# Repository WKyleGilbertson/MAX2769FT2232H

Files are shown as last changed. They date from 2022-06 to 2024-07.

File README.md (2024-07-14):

"# MAX2769FT2232H" 
This design was created to provide a hands-on platform for exploring GPS signal processing. When assembled according to the default configuration, and flashed with the appropriate FT_PROG file (L1IFStream.xml), the card should stream GPS IF data out of the USB port. The jumper configuration is selected among three different settings. It is recommended to start with the default configuration before configuring for software-controlled configuration.

This design was created because this one: https://pdfserv.maximintegrated.com/en/an/AN4275.pdf was never made available.

USBGPS

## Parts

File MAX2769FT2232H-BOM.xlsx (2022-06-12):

Item | Qty | Reference(s) | Value | LibPart | Footprint | Datasheet | Description | Digi-Key
1 | 1 | C1 | 27 pF | MAX2769FT2232H:C | MAX2769FT2232H:C_0402_1005Metric | ~ | CAP CER 27PF 50V C0G/NP0 0402 5% | 490-12651-1-ND
2 | 4 | C2, C9, C12, C46 | 470 pF | MAX2769FT2232H:C | MAX2769FT2232H:C_0402_1005Metric | ~ | CAP CER 470PF 50V C0G/NP0 0402 10% | 490-6242-1-ND
3 | 26 | C3, C4, C5, C6, C7, C8, C20, C23, C27, C29, C35, C36, C37, C38, C39, C40, C41, C42, C43, C44, C45, C49, C50, C51, C52, C53 | 100 nF | MAX2769FT2232H:C | MAX2769FT2232H:C_0402_1005Metric | ~ | CAP CER 0.1UF 16V X7R 0402 10% | 490-6328-1-ND
4 | 4 | C10, C11, C47, C48 | 10 nF | MAX2769FT2232H:C | MAX2769FT2232H:C_0402_1005Metric | ~ | CAP CER 10000PF 10V X7R 0402 10% | 399-7759-1-ND
5 | 7 | C13, C14, C15, C16, C17, C18, C19 | 100 pF | MAX2769FT2232H:C | MAX2769FT2232H:C_0402_1005Metric | ~ | CAP CER 100PF 50V C0G/NP0 0402 5% | 399-3194-1-ND
6 | 6 | C21, C24, C25, C28, C30, C31 | 1.0 uF | MAX2769FT2232H:C | MAX2769FT2232H:C_0402_1005Metric | ~ | CAP CER 1UF 6.3V X6S 0402 | 490-12233-1-ND
7 | 2 | C22, C26 | NC | MAX2769FT2232H:C | MAX2769FT2232H:C_0402_1005Metric | ~ | CAP CER 10000PF 10V X7R 0402 | 399-7759-1-ND
8 | 2 | C32, C33 | 4.7 uF | MAX2769FT2232H:C | MAX2769FT2232H:C_0805_2012Metric | ~ | CAP CER 4.7UF 6.3V X7R 0805 | 399-15725-1-ND
9 | 1 | C34 | 3.3 uF | MAX2769FT2232H:C | MAX2769FT2232H:C_0805_2012Metric | ~ | CAP CER 3.3UF 16V X7R 0805 | 490-13309-1-ND
10 | 2 | FB1, FB2 | Ferrite_Bead | MAX2769FT2232H:Ferrite_Bead | MAX2769FT2232H:L_0805_2012Metric | ~ | FERRITE BEAD 1 KOHM 0805 1LN | 490-1041-1-ND
12 | 1 | J1 | Conn_Coaxial | MAX2769FT2232H:Conn_Coaxial | MAX2769FT2232H:SMA_Amphenol_132203-12_Horizontal | ~ | CONN SMA JACK R/A 50 OHM PCB | ACX1232-ND
13 | 1 | J2 | USB_A | MAX2769FT2232H:USB_A | MAX2769FT2232H:USB_A_CNCTech_1001-011-01101_Horizontal | ~ | CONN PLUG USB2.0 TYPEA 4P SMD RA | WM3983CT-ND
14 | 1 | J3 | RF_Shield_One_Piece | MAX2769FT2232H:RF_Shield_One_Piece | MAX2769FT2232H:Laird_Technologies_BMI-S-103_26.21x26.21mm | ~ | RF SHIELD 1.032"X1.032" SLDR 1PC | 903-1008-1-ND
15 | 1 | J4 | Conn_Coaxial | MAX2769FT2232H:Conn_Coaxial | MAX2769FT2232H:MMCX_Molex_73415-1471_Vertical | ~ | CONN MMCX JACK STR 50 OHM PCB | ARF1904-ND
16 | 1 | L1 | 33 nH | MAX2769FT2232H:L | MAX2769FT2232H:L_0402_1005Metric | ~ | FIXED IND 33NH 350MA 580 MOHM | 490-2629-1-ND
17 | 1 | R1 | 20k | MAX2769FT2232H:R_US | MAX2769FT2232H:R_0603_1608Metric | ~ | RES 20K OHM 1% 1/10W 0603 | 2019-RK73H1JTTD2002FCT-ND
18 | 5 | R2, R4, R5, R7, R11 | 0 | MAX2769FT2232H:R_US | MAX2769FT2232H:R_0603_1608Metric | ~ | RES 0 OHM JUMPER 0603 | 2019-RK73Z1JTTDCT-ND
19 | 5 | R3, R6, R8, R9, R10 | NC | MAX2769FT2232H:R_US | MAX2769FT2232H:R_0603_1608Metric | ~ | RES 0 OHM JUMPER 0603 | 2019-RK73Z1JTTDCT-ND
20 | 1 | R12 | 2.2k | MAX2769FT2232H:R_US | MAX2769FT2232H:R_0603_1608Metric | ~ | RES 2.2K OHM 1% 1/10W 0603 | 2019-RK73H1JTTD2201FCT-ND
21 | 2 | R13, R17 | 1k | MAX2769FT2232H:R_US | MAX2769FT2232H:R_0603_1608Metric | ~ | RES 1K OHM 1% 1/8W 0603 | 2019-RK73H1JTTD1001FCT-ND
22 | 1 | R14 | 12k | MAX2769FT2232H:R_US | MAX2769FT2232H:R_0603_1608Metric | ~ | RES 12K OHM 1% 1/10W 0603 | 2019-RK73H1JTTD1202FCT-ND
23 | 3 | R15, R16, R18 | 10k | MAX2769FT2232H:R_US | MAX2769FT2232H:R_0603_1608Metric | ~ | RES 10K OHM 1% 1/10W 0603 | 2019-RK73H1JTTD1002FCT-ND
24 | 1 | U1 | MAX2769ETI+T | MAX2769FT2232H:MAX2769ETI+T | MAX2769FT2232H:MAX2769ETI&plus_T |  | RF RX GNSS 1575.42MHZ 28TQFN | MAX2769BETI/V+-ND
25 | 2 | U2, U3 | TPS717285DCKR | MAX2769FT2232H:TPS717285DCKR | MAX2769FT2232H:TPS717285DCKR |  | IC REG LINEAR 2.85V 150MA SC70-5 | 296-19649-1-ND
26 | 1 | U4 | NCP164CSN330T1G | MAX2769FT2232H:NCP164CSN330T1G | MAX2769FT2232H:TSOT-23-5 | https://www.onsemi.com/pub/Collateral/NCP164C-D.PDF | LDO 300 MA AD 3.3V, ULTRA | 488-NCP164CSN330T1GCT-ND
27 | 1 | U5 | 93LC66BT-I_OT | MAX2769FT2232H:93LC66BT-I_OT | MAX2769FT2232H:93LC66BT-I&slash_OT |  | IC EEPROM 4K SPI 2MHZ SOT23-6 | 93LC66BT-I/OTCT-ND
28 | 1 | U6 | FT2232H-Interface_USB | MAX2769FT2232H:FT2232H-Interface_USB | MAX2769FT2232H:LQFP-64_10x10mm_P0.5mm |  | IC USB HS DUAL UART/FIFO 64-LQFP | 768-1024-1-ND
29 | 1 | U7 | 74LVC1G74 | MAX2769FT2232H:74LVC1G74 | MAX2769FT2232H:SOT-833-1 | https://assets.nexperia.com/documents/data-sheet/74LVC1G74.pdf | IC FF D-TYPE SNGL 1BIT 8XSON | 1727-3558-1-ND
30 | 1 | U8 | 74LVC1G04 | MAX2769FT2232H:74LVC1G04 | MAX2769FT2232H:SOT-353_SC-70-5 | https://assets.nexperia.com/documents/data-sheet/74LVC1G04.pdf | IC INVERTER 1CH 1-INP 5TSSOP | 1727-2871-1-ND
31 | 2 | U9, U10 | 74LVC374 | MAX2769FT2232H:74LVC374 | MAX2769FT2232H:TSSOP-20_4.4x6.5mm_P0.65mm | https://assets.nexperia.com/documents/data-sheet/74LVC374A.pdf | IC FF D-TYPE SNGL 8BIT 20TSSOP | 1727-4034-1-ND
32 | 1 | U11 | 74HC2G04 | MAX2769FT2232H:74HC2G04 | MAX2769FT2232H:SOT-363_SC-70-6 | https://assets.nexperia.com/documents/data-sheet/74HC_HCT2G04.pdf | IC INVERTER 2CH 2-INP 6TSSOP | 1727-6045-1-ND
33 | 1 | X1 | Taiten-16.368MHz | MAX2769FT2232H:Taiten-16.368MHz | MAX2769FT2232H:TXETCDSANF-16.368000 |  | XTAL OSC TCXO 16.3680MHZ SNWV | 1664-1271-1-ND
34 | 1 | X2 | SIT2024BA-S8-33E-12.00000E | MAX2769FT2232H:SIT2024BA-S8-33E-12.00000E | MAX2769FT2232H:SIT2024BA-S8-33E-8.000000E |  | MEMS OSC XO 12.0000MHZ LVCMOS LV | 1473-SIT2024BA-S8-33E-12.000000G-ND

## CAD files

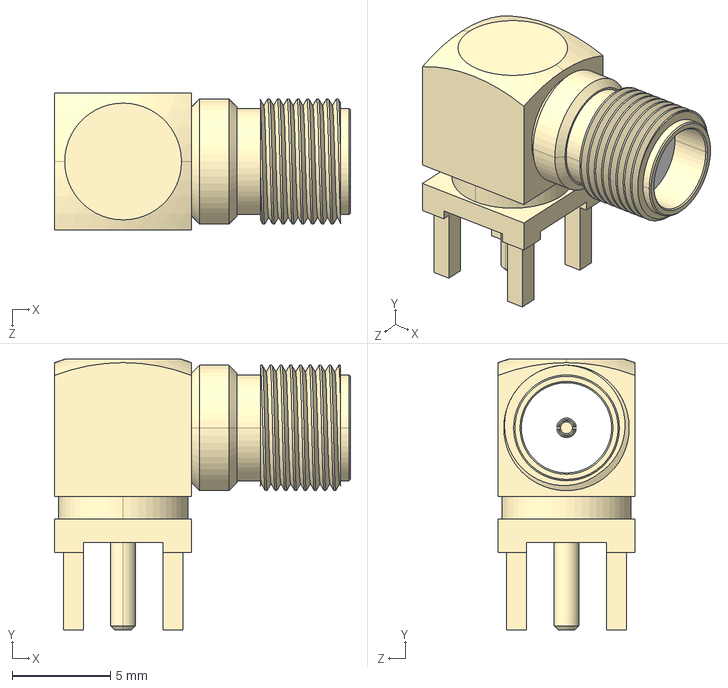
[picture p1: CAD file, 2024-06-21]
STEP-Files/901-143-6RFX.STEP
15.1 x 13.8 x 7.00 mm

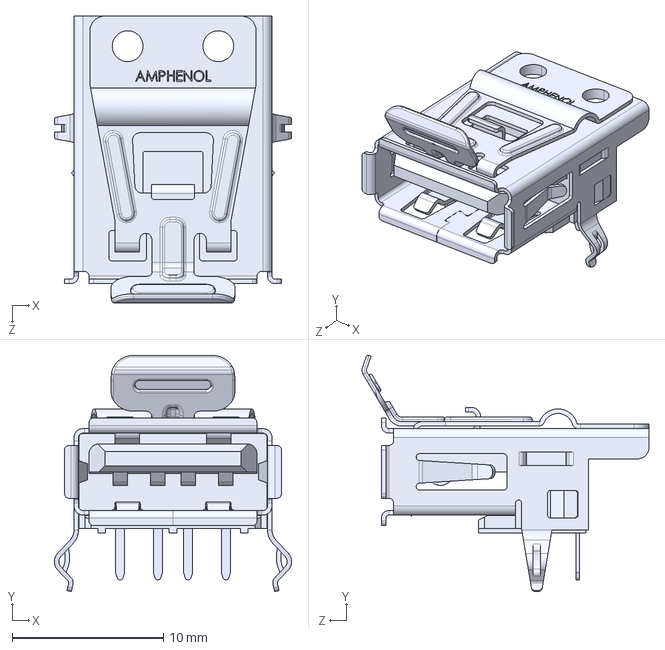
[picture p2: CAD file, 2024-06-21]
STEP-Files/ACC-M-LUSB-A111-00-REVT3.STEP
15.7 x 15.6 x 19.0 mm

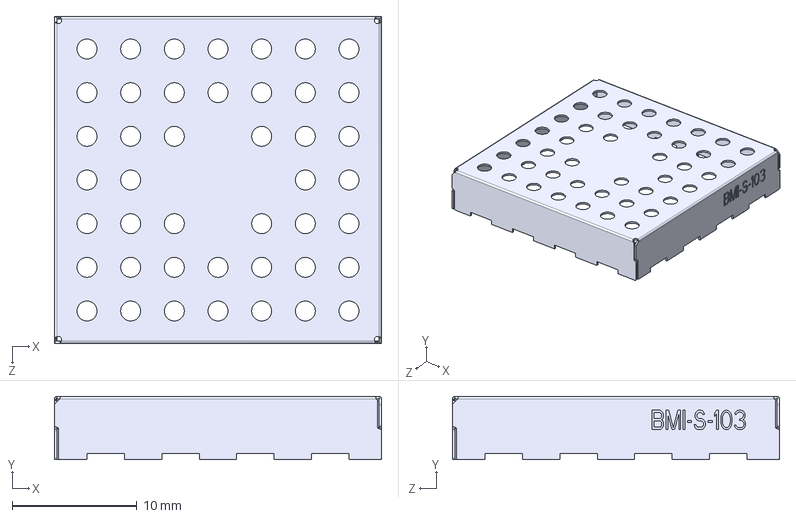
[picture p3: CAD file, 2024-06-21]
STEP-Files/User Library-Laird-BMI-S-103-1.STEP
26.2 x 5.08 x 26.2 mm

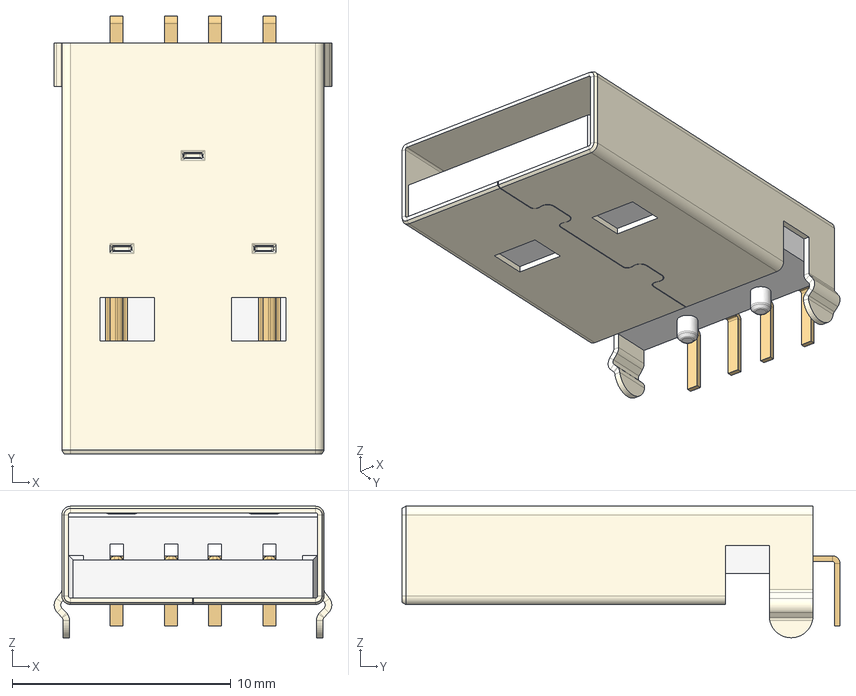
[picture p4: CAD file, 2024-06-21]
STEP-Files/USB-A Right Angle Solder Plug.stp
12.7 x 20.0 x 6.02 mm
USB-A Right Angle Solder Plug Shell
USB-A Right Angle Solder Plug Inlay
USB-A Right Angle Solder Plug Contact 1 x 2
USB-A Right Angle Solder Plug Contact 2 x 2

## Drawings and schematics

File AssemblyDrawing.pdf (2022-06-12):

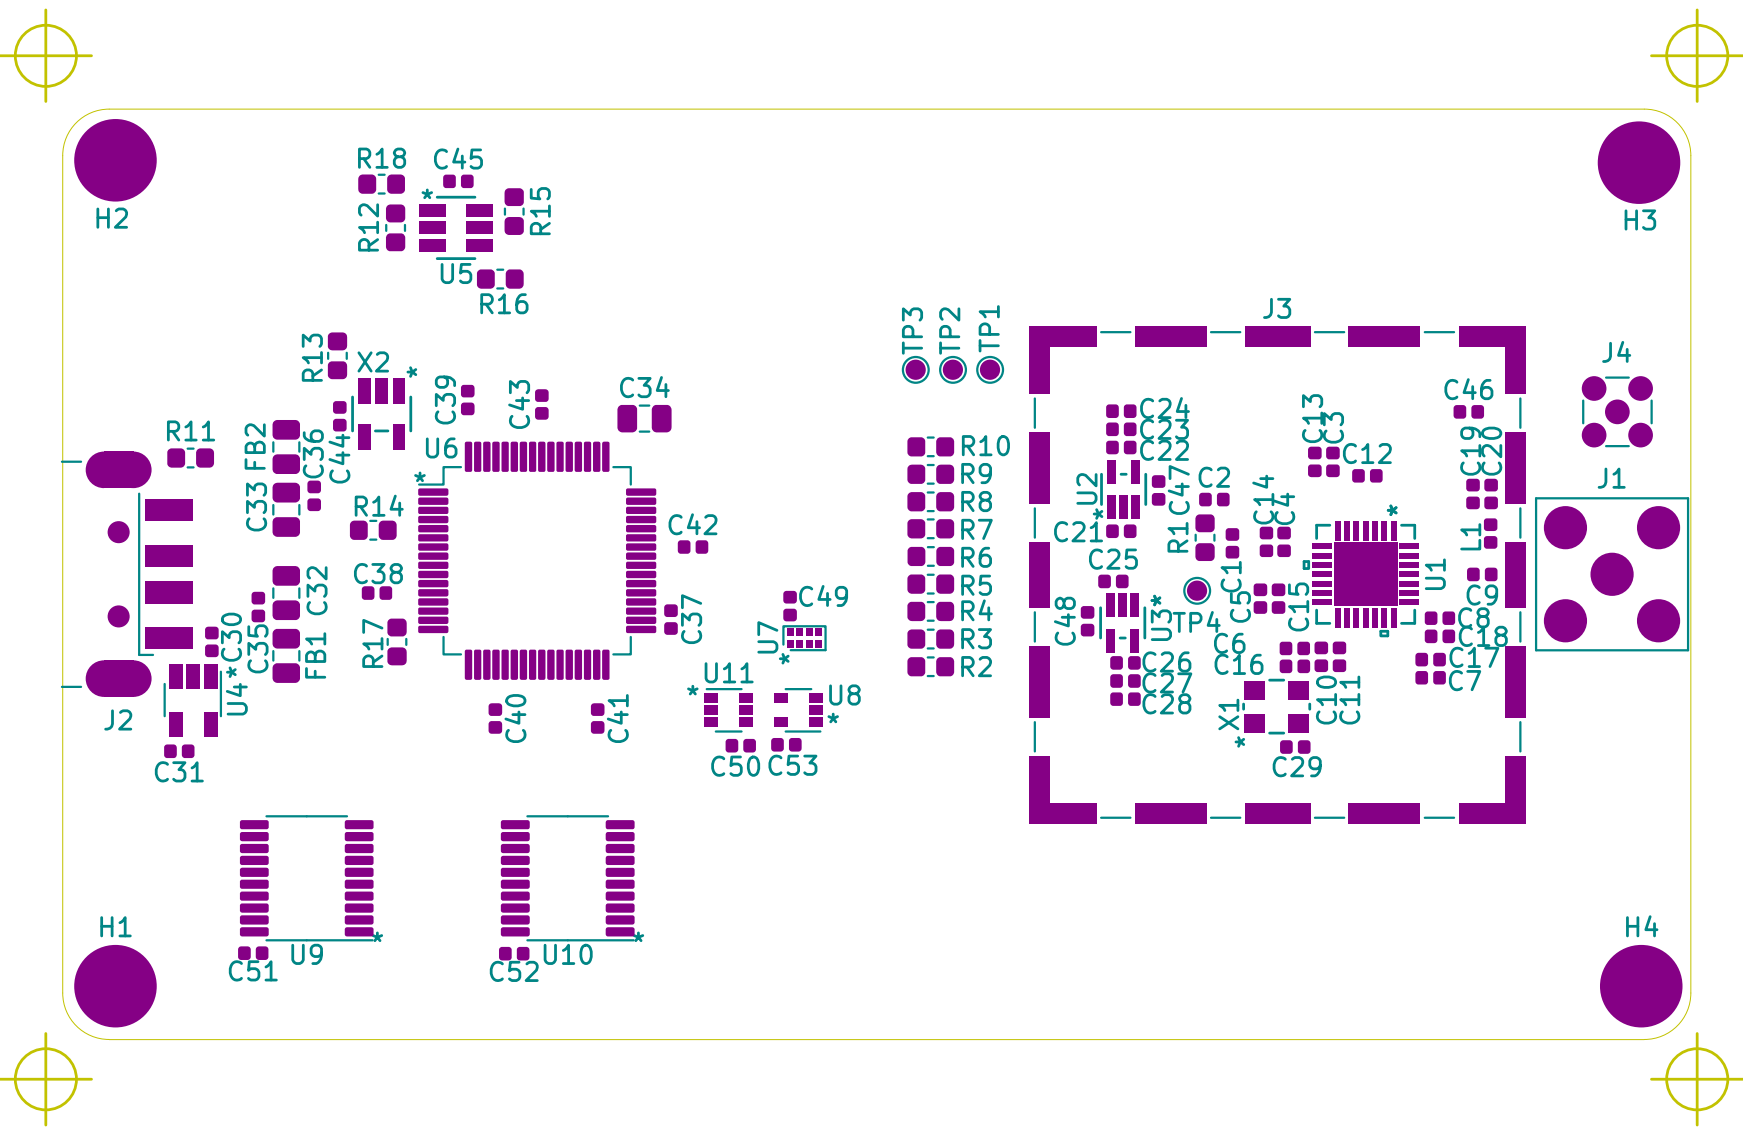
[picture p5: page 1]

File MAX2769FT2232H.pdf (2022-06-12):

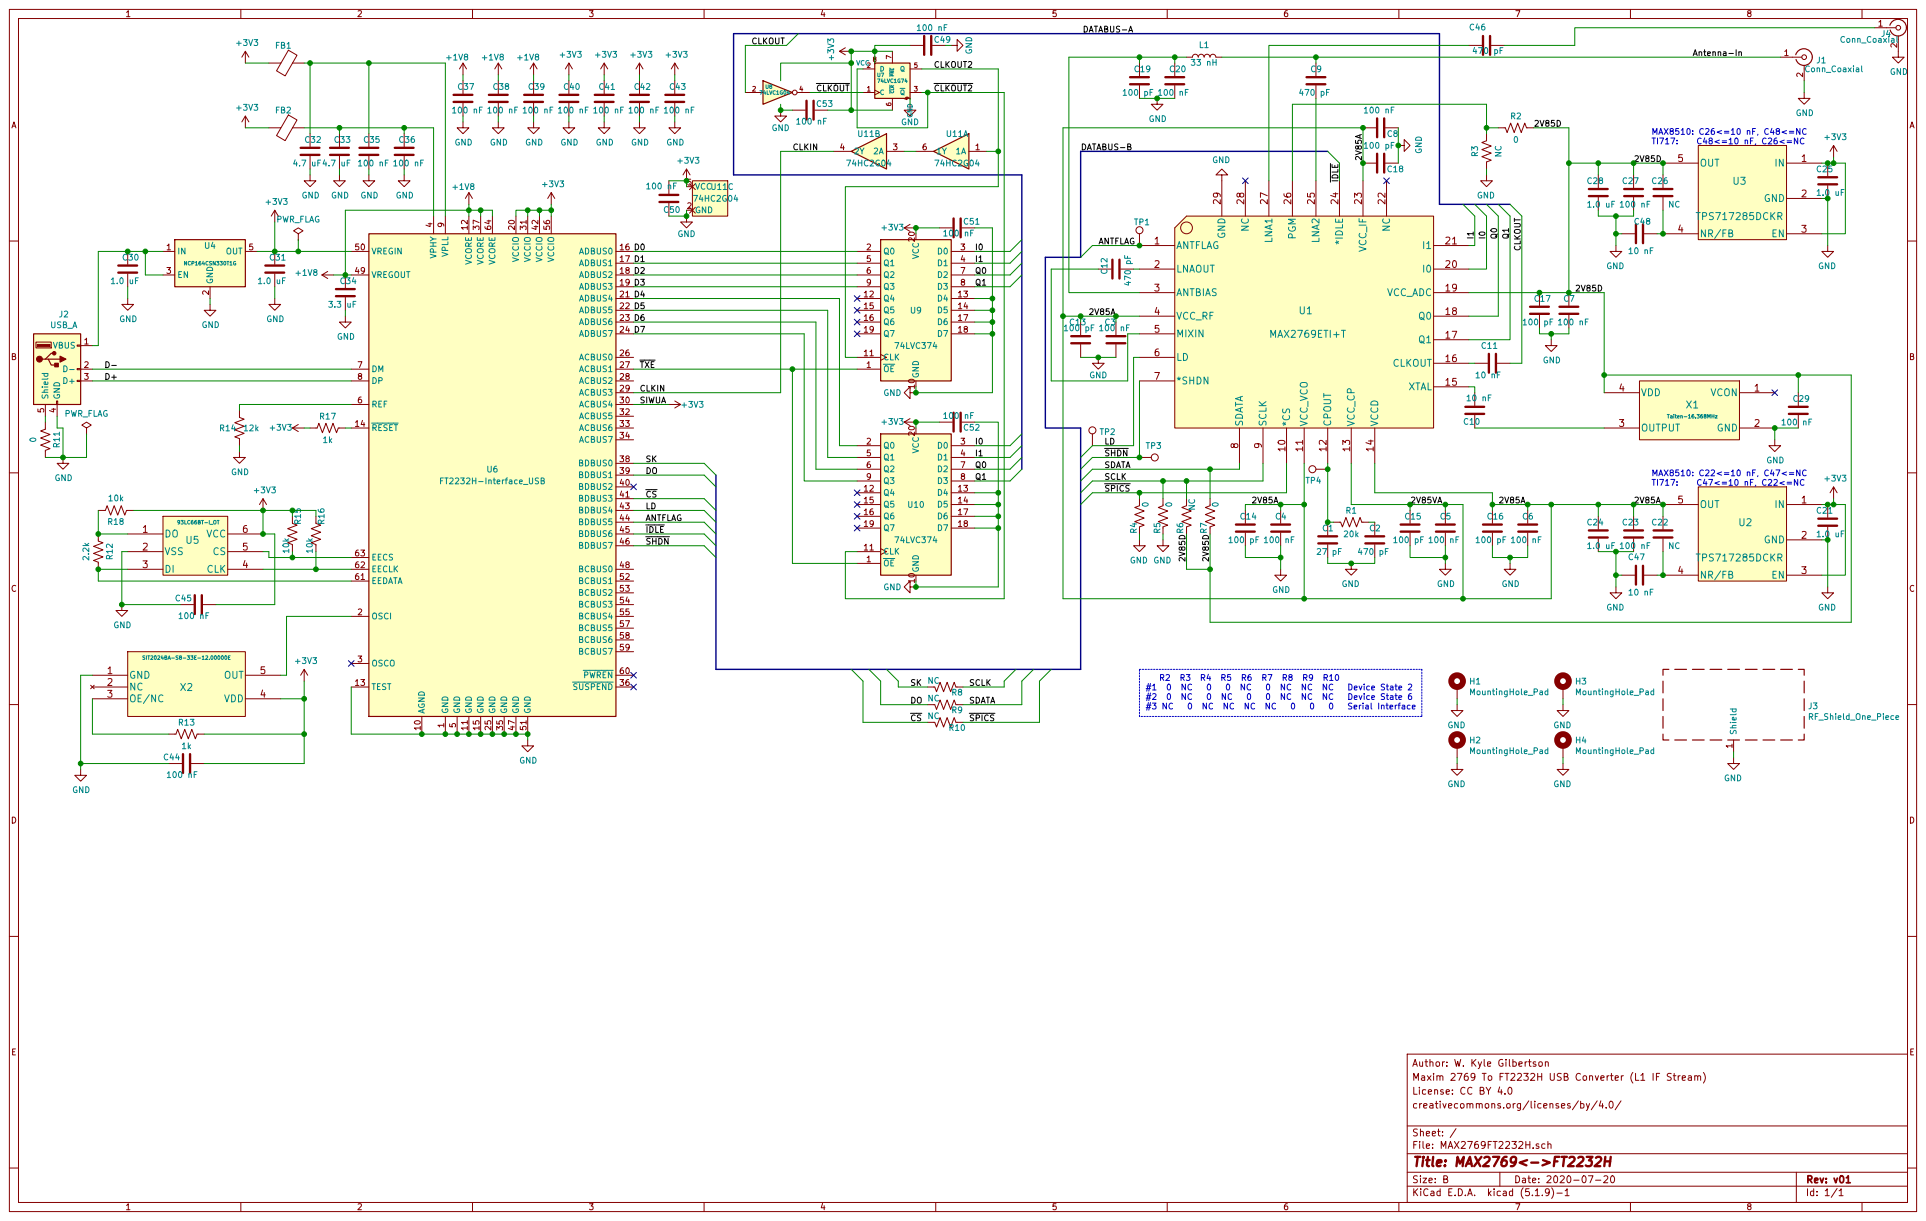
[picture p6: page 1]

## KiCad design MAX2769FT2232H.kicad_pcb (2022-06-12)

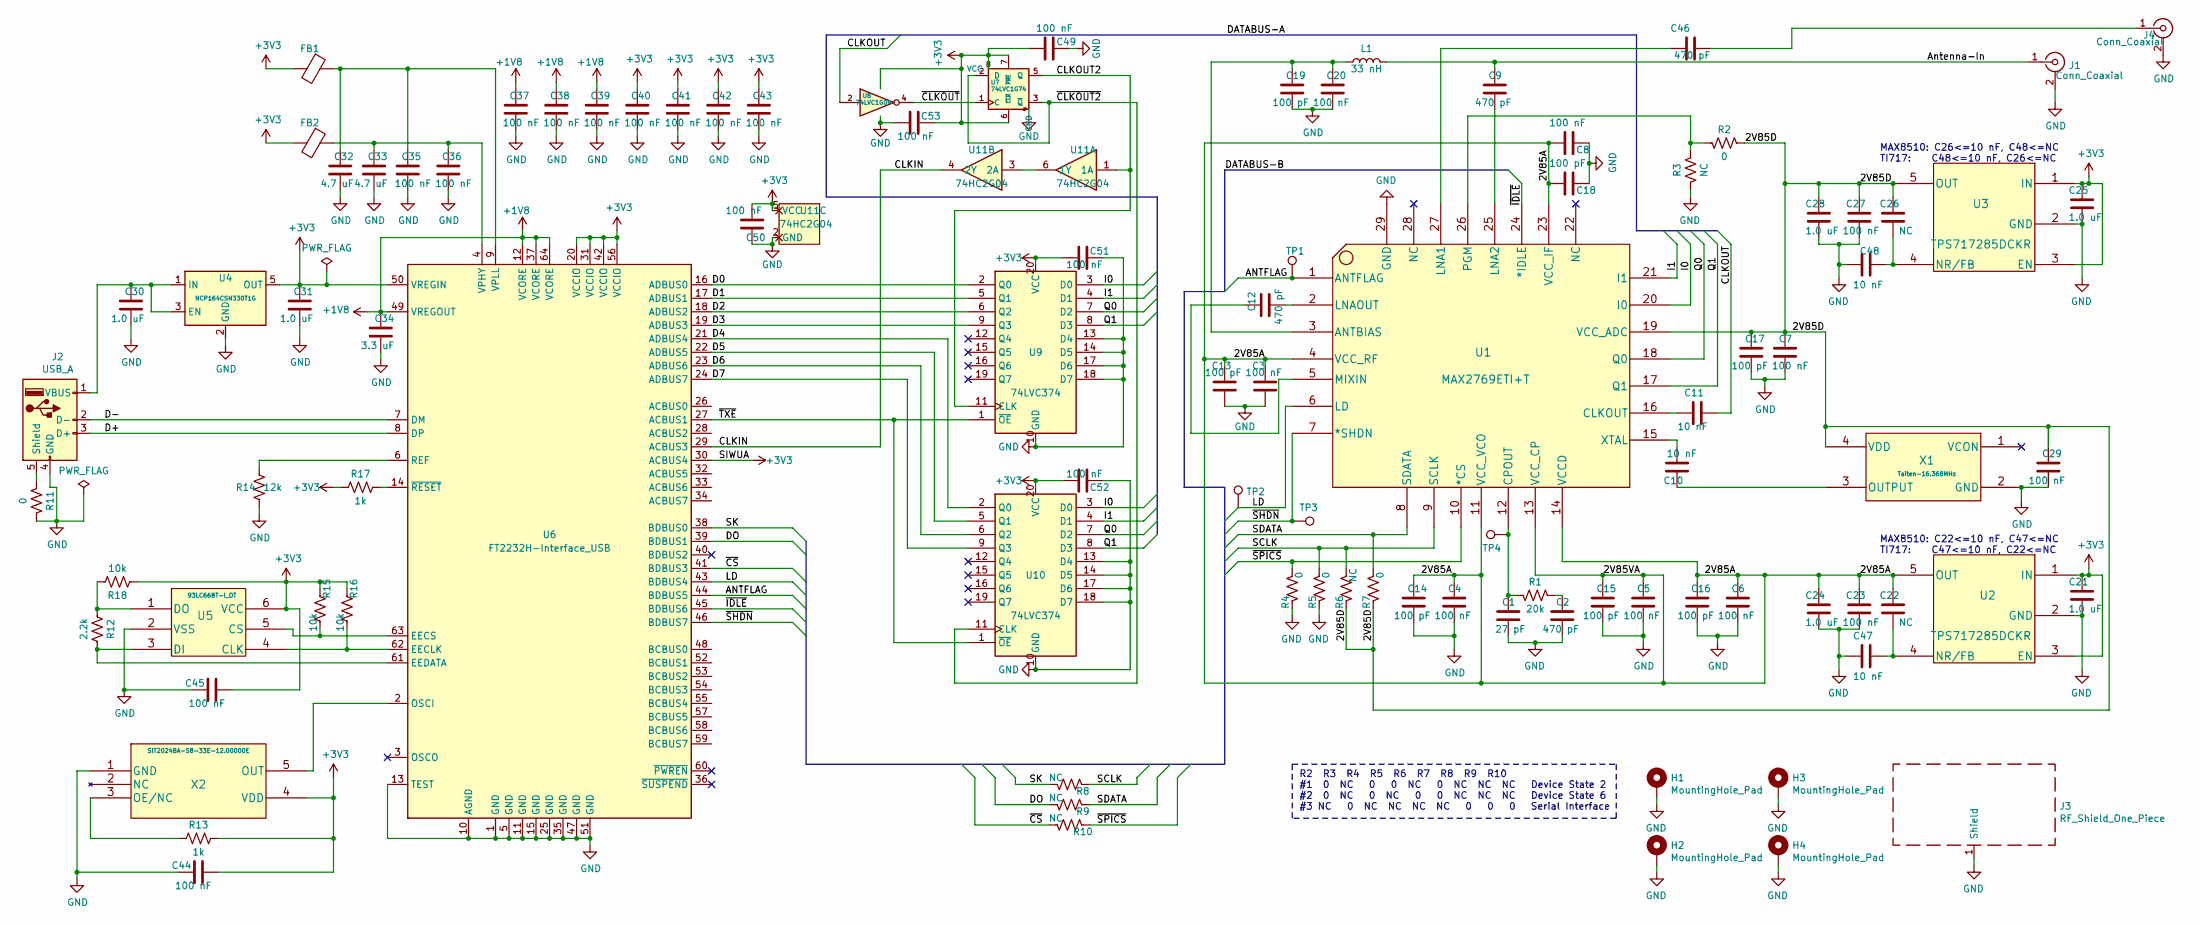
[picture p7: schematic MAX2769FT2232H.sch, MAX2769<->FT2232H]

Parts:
C1: 27 pF; C_0402_1005Metric; Digi-Key 490-12651-1-ND
C2, C9, C12, C46: 470 pF; C_0402_1005Metric; Digi-Key 490-6242-1-ND
C3, C4, C5, C6, C7, C8, C20, C23, C27, C29, C35, C36, C37, C38, C39, C40, C41, C42, C43, C44, C45, C49, C50, C51, C52, C53: 100 nF; C_0402_1005Metric; Digi-Key 490-6328-1-ND
C10, C11, C47, C48: 10 nF; C_0402_1005Metric; Digi-Key 399-7759-1-ND
C13, C14, C15, C16, C17, C18, C19: 100 pF; C_0402_1005Metric; Digi-Key 399-3194-1-ND
C21, C24, C25, C28, C30, C31: 1.0 uF; C_0402_1005Metric; Digi-Key 490-12233-1-ND
C22, C26: NC; C_0402_1005Metric; Digi-Key 399-7759-1-ND
C32, C33: 4.7 uF; C_0805_2012Metric; Digi-Key 399-15725-1-ND
C34: 3.3 uF; C_0805_2012Metric; Digi-Key 490-13309-1-ND
FB1, FB2: Ferrite_Bead; L_0805_2012Metric; Digi-Key 490-1041-1-ND
H1, H2, H3, H4: MountingHole_Pad; MountingHole_2.2mm_M2_Pad_Via
J1: Conn_Coaxial; SMA_Amphenol_132203-12_Horizontal; Digi-Key ACX1232-ND
J2: USB_A; USB_A_CNCTech_1001-011-01101_Horizontal; Digi-Key WM3983CT-ND
J3: RF_Shield_One_Piece; Laird_Technologies_BMI-S-103_26.21x26.21mm; Digi-Key 903-1008-1-ND
J4: Conn_Coaxial; MMCX_Molex_73415-1471_Vertical; Digi-Key ARF1904-ND
L1: 33 nH; L_0402_1005Metric; Digi-Key 490-2629-1-ND
R1: 20k; R_0603_1608Metric; Digi-Key 2019-RK73H1JTTD2002FCT-ND
R2, R4, R5, R7, R11: 0; R_0603_1608Metric; Digi-Key 2019-RK73Z1JTTDCT-ND
R3, R6, R8, R9, R10: NC; R_0603_1608Metric; Digi-Key 2019-RK73Z1JTTDCT-ND
R12: 2.2k; R_0603_1608Metric; Digi-Key 2019-RK73H1JTTD2201FCT-ND
R13, R17: 1k; R_0603_1608Metric; Digi-Key 2019-RK73H1JTTD1001FCT-ND
R14: 12k; R_0603_1608Metric; Digi-Key 2019-RK73H1JTTD1202FCT-ND
R15, R16, R18: 10k; R_0603_1608Metric; Digi-Key 2019-RK73H1JTTD1002FCT-ND
TP1, TP2, TP3, TP4: TestPoint; TestPoint_Pad_D1.0mm
U1: MAX2769ETI+T; MAX2769ETI&plus_T; Digi-Key MAX2769BETI/V+-ND
U2, U3: TPS717285DCKR; Digi-Key 296-19649-1-ND
U4: NCP164CSN330T1G; TSOT-23-5; Digi-Key 488-NCP164CSN330T1GCT-ND
U5: 93LC66BT-I_OT; 93LC66BT-I&slash_OT; Digi-Key 93LC66BT-I/OTCT-ND
U6: FT2232H-Interface_USB; LQFP-64_10x10mm_P0.5mm; Digi-Key 768-1024-1-ND
U7: 74LVC1G74; SOT-833-1; Digi-Key 1727-3558-1-ND
U8: 74LVC1G04; SOT-353_SC-70-5; Digi-Key 1727-2871-1-ND
U9, U10: 74LVC374; TSSOP-20_4.4x6.5mm_P0.65mm; Digi-Key 1727-4034-1-ND
U11: 74HC2G04; SOT-363_SC-70-6
X1: Taiten-16.368MHz; TXETCDSANF-16.368000; Digi-Key 1664-1271-1-ND
X2: SIT2024BA-S8-33E-12.00000E; SIT2024BA-S8-33E-8.000000E; Digi-Key 1473-SIT2024BA-S8-33E-12.000000G-ND

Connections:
+1V8: C34.1, C37.1, C38.1, C39.1, U6.12 (VCORE), U6.37 (VCORE), U6.49 (VREGOUT), U6.64 (VCORE)
+3V3: C21.1, C25.1, C31.1, C40.1, C41.1, C42.1, C43.1, C44.2, C45.2, C49.2, C50.2, C51.1, C52.1, C53.2, FB1.2, FB2.2, R13.1, R15.2, R16.2, R17.2, R18.2, U2.1 (IN), U2.3 (EN), U3.1 (IN), U3.3 (EN), U4.5 (OUT), U5.6 (VCC), U6.20 (VCCIO), U6.30 (ACBUS4), U6.31 (VCCIO), U6.42 (VCCIO), U6.50 (VREGIN), U6.56 (VCCIO), U7.6 (~CLR), U7.7 (~PRE), U7.8 (VCC), U8.5 (VCC), U9.20 (VCC), U10.20 (VCC), U11.5 (VCC), X2.4 (VDD)
/2V85A: C3.1, C4.1, C5.1, C6.1, C8.2, C13.1, C14.1, C15.1, C16.1, C18.2, C22.1, C23.1, C24.1, U1.4 (VCC_RF), U1.11 (VCC_VCO), U1.13 (VCC_CP), U1.14 (VCCD), U1.23 (VCC_IF), U2.5 (OUT)
/2V85D: C7.1, C17.1, C26.1, C27.1, C28.1, C29.1, R2.2, R6.2, R7.2, U1.19 (VCC_ADC), U3.5 (OUT), X1.4 (VDD)
/ANTFLAG: TP1.1, U1.1 (ANTFLAG), U6.44 (BDBUS5)
/Antenna-In: C9.1, J1.1 (In), L1.2
/CLKIN: U6.29 (ACBUS3), U11.4 (2Y)
/CLKOUT: C11.1, U8.2
/CLKOUT2: U7.5 (Q), U9.11 (CLK), U11.1 (1A)
/D0: U6.16 (ADBUS0), U9.2 (Q0)
/D1: U6.17 (ADBUS1), U9.5 (Q1)
/D2: U6.18 (ADBUS2), U9.6 (Q2)
/D3: U6.19 (ADBUS3), U9.9 (Q3)
/D4: U6.21 (ADBUS4), U10.2 (Q0)
/D5: U6.22 (ADBUS5), U10.5 (Q1)
/D6: U6.23 (ADBUS6), U10.6 (Q2)
/D7: U6.24 (ADBUS7), U10.9 (Q3)
/D+: J2.3 (D+), U6.8 (DP)
/D-: J2.2 (D-), U6.7 (DM)
/DO: R9.2, U6.39 (BDBUS1)
/I0: U1.20 (I0), U9.3 (D0), U10.3 (D0)
/I1: U1.21 (I1), U9.4 (D1), U10.4 (D1)
/LD: TP2.1, U1.6 (LD), U6.43 (BDBUS4)
/Q0: U1.18 (Q0), U9.7 (D2), U10.7 (D2)
/Q1: U1.17 (Q1), U9.8 (D3), U10.8 (D3)
/SCLK: R5.2, R6.1, R8.1, U1.9 (SCLK)
/SDATA: R7.1, R9.1, U1.8 (SDATA)
/SK: R8.2, U6.38 (BDBUS0)
/~CLKOUT: U7.1 (C), U8.4
/~CLKOUT2: U7.2 (D), U7.3 (~Q), U10.11 (CLK)
/~CS: R10.2, U6.41 (BDBUS3)
/~IDLE: U1.24 (*IDLE), U6.45 (BDBUS6)
/~SHDN: TP3.1, U1.7 (*SHDN), U6.46 (BDBUS7)
/~SPICS: R4.2, R10.1, U1.10 (*CS)
/~TXE: U6.27 (ACBUS1), U9.1 (~OE), U10.1 (~OE)
GND: C1.2, C2.2, C3.2, C4.2, C5.2, C6.2, C7.2, C8.1, C13.2, C14.2, C15.2, C16.2, C17.2, C18.1, C19.2, C20.2, C21.2, C23.2, C24.2, C25.2, C27.2, C28.2, C29.2, C30.2, C31.2, C32.2, C33.2, C34.2, C35.2, C36.2, C37.2, C38.2, C39.2, C40.2, C41.2, C42.2, C43.2, C44.1, C45.1, C47.2, C48.2, C49.1, C50.1, C51.2, C52.2, C53.1, H1.1, H2.1, H3.1, H4.1, J1.2 (Ext), J2.4 (GND), J3.1, J4.2 (Ext), R3.1, R4.1, R5.1, R11.2, R14.2, U1.29 (GND), U2.2 (GND), U3.2 (GND), U4.2 (GND), U5.2 (VSS), U6.1 (GND), U6.5 (GND), U6.10 (AGND), U6.11 (GND), U6.13 (TEST), U6.15 (GND), U6.25 (GND), U6.35 (GND), U6.47 (GND), U6.51 (GND), U7.4 (GND), U8.3 (GND), U9.10 (GND), U9.13 (D4), U9.14 (D5), U9.17 (D6), U9.18 (D7), U10.10 (GND), U10.13 (D4), U10.14 (D5), U10.17 (D6), U10.18 (D7), U11.2 (GND), X1.2 (GND), X2.1 (GND)
unnamed: C1.1, R1.1, TP4.1, U1.12 (CPOUT)
unnamed: C2.1, R1.2
unnamed: C9.2, U1.25 (LNA2)
unnamed: C10.1, X1.3 (OUTPUT)
unnamed: C10.2, U1.15 (XTAL)
unnamed: C11.2, U1.16 (CLKOUT)
unnamed: C12.1, U1.5 (MIXIN)
unnamed: C12.2, U1.2 (LNAOUT)
unnamed: C19.1, C20.1, L1.1, U1.3 (ANTBIAS)
unnamed: C22.2, C47.1, U2.4 (NR/FB)
unnamed: C26.2, C48.1, U3.4 (NR/FB)
unnamed: C30.1, J2.1 (VBUS), U4.1 (IN), U4.3 (EN)
unnamed: C32.1, C35.1, FB1.1, U6.9 (VPLL)
unnamed: C33.1, C36.1, FB2.1, U6.4 (VPHY)
unnamed: C46.1, U1.27 (LNA1)
unnamed: C46.2, J4.1 (In)
unnamed: J2.5 (Shield), R11.1
unnamed: R2.1, R3.2, U1.26 (PGM)
unnamed: R12.1, U5.3 (DI), U6.61 (EEDATA)
unnamed: R12.2, R18.1, U5.1 (DO)
unnamed: R13.2, X2.3 (OE/NC)
unnamed: R14.1, U6.6 (REF)
unnamed: R15.1, U5.5 (CS), U6.63 (EECS)
unnamed: R16.1, U5.4 (CLK), U6.62 (EECLK)
unnamed: R17.1, U6.14 (~RESET)
unnamed: U6.2 (OSCI), X2.5 (OUT)
unnamed: U11.3 (2A), U11.6 (1Y)

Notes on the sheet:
R2 R3 R4 R5 R6 R7 R8 R9 R10 #1 0 NC 0 0 NC 0 NC NC NC Device State 2 #2 0 NC 0 NC 0 0 NC NC NC Device State 6 #3 NC 0 NC NC NC NC 0 0 0 Serial Interface
MAX8510: C26<=10 nF, C48<=NC TI717: C48<=10 nF, C26<=NC
MAX8510: C22<=10 nF, C47<=NC TI717: C47<=10 nF, C22<=NC

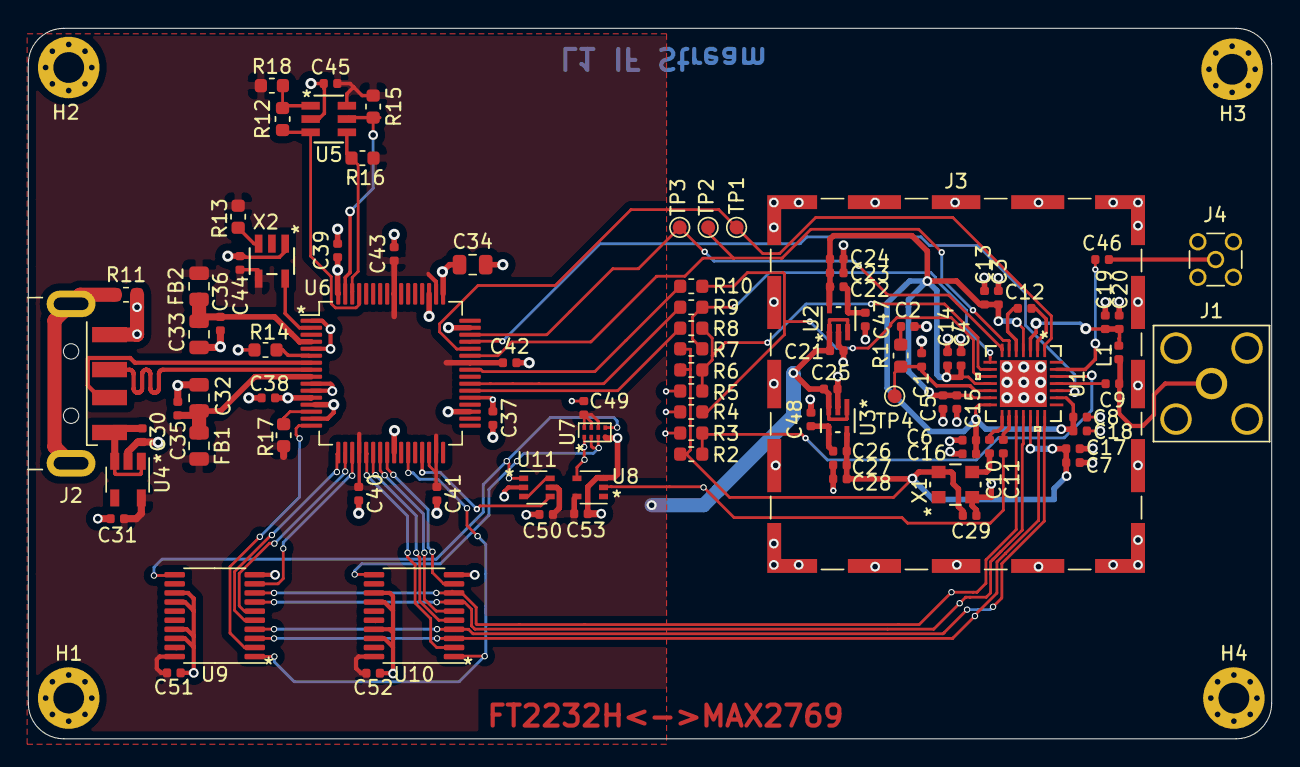
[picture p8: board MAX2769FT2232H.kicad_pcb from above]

Board: 4 copper layers, 88.9 x 50.8 mm, 99 parts (0 on the bottom side), 63 nets.

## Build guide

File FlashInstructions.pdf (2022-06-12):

If the file, [L1IFStream.xml] doesn't work:
Make a new template from scratch. These are the steps to follow:
1) Run FT_PROG.exe
2) File->"New Template"
3) Click on "Chip Details"
4) Type: Pulldown to "FT2232H"
5) Click + in front of "Hardware Specific"
6) Click + in front of "Port A"
7) Click on "Hardware"
8) Select radio button after "245 FIFO"
9) Click on "Driver"
10) Leave radio button in default position, "Virtual COM Port"
11) Click on + in front of "Port B"
12) Click on "Hardware"
13) Select radio button after "OPTO Isolate"
14) Click on "Driver"
15) Select radio button value for "D2XX Direct"
16) File->"Save As Template"
17) Give the template a name and save it.
18) Devices->"Scan and Parse"
19) Right click on "Device: 0[LocID:0x111]"->"Erase Device"
20) Right click on "Device: 0[LocID:0x111]"->"Apply Template" Select the current template (under "From File")
21) Right click on "Device: 0[LocID:0x111]"->"Program Device"
22) Right click on "Device: 0[LocID:0x111]"->"Cycle Port"
23) Right click on "Device: 0[LocID:0x111]"->"Re-Scan Device"
24) Verify settings survived recycle.
25) Right click on "Device: 0[LocID:0x111]"->"Close Device"
26) Use Ports in Device Manager to determine COM port number
27) Open TerraTerm in Serial mode, select the COM port number
28) The window should look like the image below

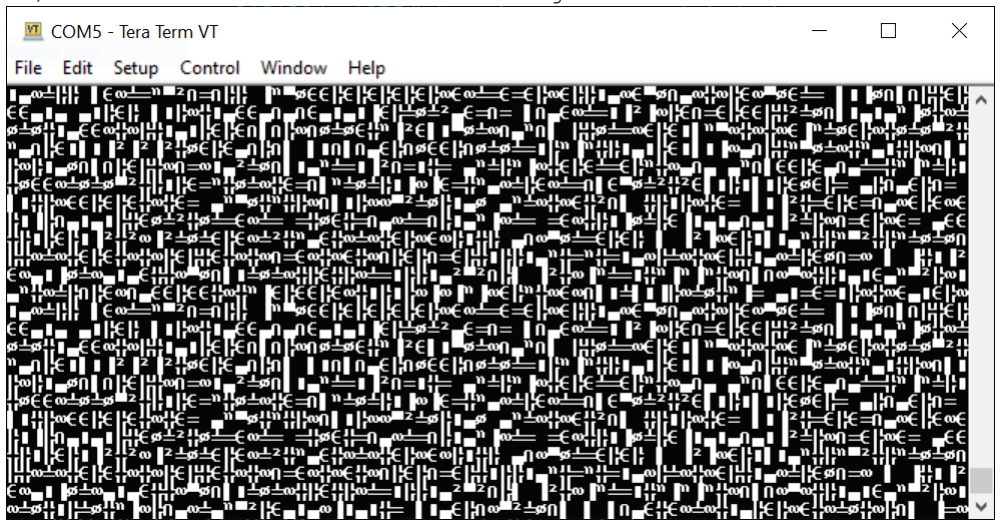
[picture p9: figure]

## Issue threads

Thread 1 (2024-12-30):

Practical use

danielkucera, 2024-12-30:
Hi @WKyleGilbertson ,

did you also manage to make it work with some PC software? What was your target?

WKyleGilbertson, 2024-12-30:
I wrote some PC software that does work with this card. It works on Windows, MacOS, and Linux using the FTD2XX drivers. The resultant capture files will produce solutions through [GNSS-SDR](https://gnss-sdr.org/) with the proper adjustments to the config file. It's possible some additional adjustments could be made to make the card run live solutions. I've switched gears to another approach that is more likely to support live solutions.

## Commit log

2021-04-15 Adding Design Files
    [BoardConfig.txt, MAX2769FT2232H.kicad_pcb, MAX2769FT2232H.sch]
2021-04-17 Setup PCB new to only show assembly view
2021-04-19 First Pass BOM
    [MAX2769FT2232H.csv]
2022-06-12 Added Note concerning voltage regulator caps
    [MAX2769FT2232H.kicad_pcb, MAX2769FT2232H.sch]
2022-06-12 Voltage Regulator Circuit
    Added note to schematic regarding capacitors used with different voltage regulators
    [MAX2769FT2232H-BOM.xlsx, MAX2769FT2232H.xlsx]
2022-06-12 Added pdf of schematic
2022-06-12 Added Assembly Drawing
2023-06-26 Added board image
2023-06-28 Added STEP files
    [901-143-6RFX.STEP, ACC-M-LUSB-A111-00-REVT3.STEP, USB-A Right Angle Solder Plug.stp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]

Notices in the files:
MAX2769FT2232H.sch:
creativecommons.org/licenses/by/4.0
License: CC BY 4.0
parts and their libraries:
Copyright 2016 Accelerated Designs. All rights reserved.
